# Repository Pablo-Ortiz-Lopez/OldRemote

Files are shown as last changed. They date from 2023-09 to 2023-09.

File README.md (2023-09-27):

## OldRemote

This repository consists of the reverse engineering of a garage remote design by spanish company JCM dated around 1995. It emits an ASK signal, which encodes the value of a physical trinary selector, using a 280MHz carrier wave.

### Contents
This repository contains the following files
* Schematic of the design (KiCad)
* Approximate PCB Layout of the design (KiCad)
* Datasheets of various components used

For more information, don't hesitate to check out my blog: [ortizma.com](https://ortizma.com), or contact me via [pabloortiz132@gmail.com](mailto:pabloortiz132@gmail.com)

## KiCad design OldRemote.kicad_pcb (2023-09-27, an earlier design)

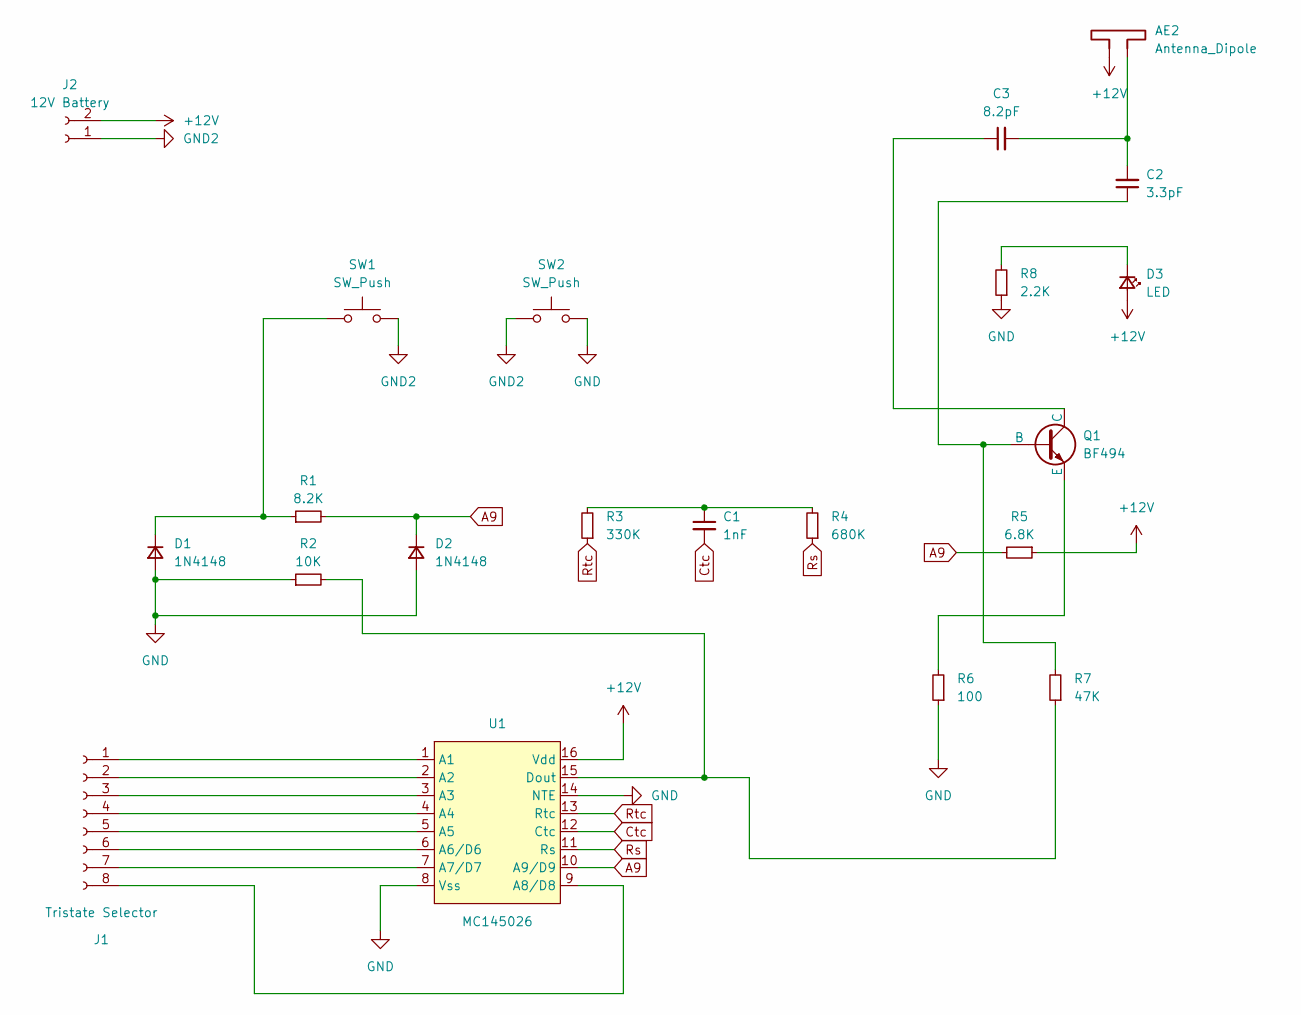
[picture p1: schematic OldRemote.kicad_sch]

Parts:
AE2: Antenna_Dipole; PinSocket_1x02_P2.54mm_Vertical
C1: 1nF; C_Rect_L4.0mm_W2.5mm_P2.50mm
C2: 3.3pF; C_Disc_D3.0mm_W1.6mm_P2.50mm
C3: 8.2pF; C_Disc_D3.0mm_W1.6mm_P2.50mm
D1, D2: 1N4148; D_DO-35_SOD27_P7.62mm_Horizontal
D3: LED; LED_D3.0mm_FlatTop
J1: Tristate Selector; PinSocket_1x08_P2.54mm_Horizontal
J2: 12V Battery; PinSocket_1x02_P2.54mm_Vertical
Q1: BF494; TO-92
R1: 8.2K; R_Axial_DIN0204_L3.6mm_D1.6mm_P5.08mm_Horizontal
R2: 10K; R_Axial_DIN0204_L3.6mm_D1.6mm_P5.08mm_Horizontal
R3: 330K; R_Axial_DIN0204_L3.6mm_D1.6mm_P5.08mm_Horizontal
R4: 680K; R_Axial_DIN0204_L3.6mm_D1.6mm_P5.08mm_Horizontal
R5: 6.8K; R_Axial_DIN0204_L3.6mm_D1.6mm_P5.08mm_Horizontal
R6: 100; R_Axial_DIN0204_L3.6mm_D1.6mm_P5.08mm_Horizontal
R7: 47K; R_Axial_DIN0204_L3.6mm_D1.6mm_P5.08mm_Horizontal
R8: 2.2K; R_Axial_DIN0204_L3.6mm_D1.6mm_P5.08mm_Horizontal
SW1, SW2: SW_Push; 4.5mm switch
U1: MC145026; DIP-16_W7.62mm

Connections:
+12V: AE2.1, D3.2 (A), J2.2, R5.1, U1.16 (Vdd)
A9: D2.1 (K), R1.2, R5.2, U1.10 (A9/D9)
Ctc: C1.2, U1.12 (Ctc)
GND: D1.2 (A), D2.2 (A), R2.1, R6.1, R8.1, SW2.2, U1.8 (Vss), U1.14 (NTE)
GND2: J2.1, SW1.2, SW2.1
unnamed: AE2.2, C2.2, C3.2
unnamed: C1.1, R3.2, R4.2
unnamed: D1.1 (K), R1.1, SW1.1
unnamed: D3.1 (K), R8.2
unnamed: J1.1, U1.1 (A1)
unnamed: J1.2, U1.2 (A2)
unnamed: J1.3, U1.3 (A3)
unnamed: J1.4, U1.4 (A4)
unnamed: J1.5, U1.5 (A5)
unnamed: J1.6, U1.6 (A6/D6)
unnamed: J1.7, U1.7 (A7/D7)
unnamed: J1.8, U1.9 (A8/D8)
unnamed: C2.1, Q1.2 (B), R7.2
unnamed: C3.1, Q1.1 (C)
unnamed: Q1.3 (E), R6.2
unnamed: R2.2, R7.1, U1.15 (Dout)
Rs: R4.1, U1.11 (Rs)
Rtc: R3.1, U1.13 (Rtc)

Board: 2 copper layers, 21 parts (0 on the bottom side), 23 nets, no tracks yet.

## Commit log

2023-09-27 Add trinary encoder datasheet
2023-09-29 Update schematic
    [OldRemote.kicad_sch]
